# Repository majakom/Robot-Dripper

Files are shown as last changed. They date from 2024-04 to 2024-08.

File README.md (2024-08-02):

# Robot-Dripper

Project made for Computer System Architecture at Poznań University of Technology.

## General description of the project

The goal of this project was to create a robot that is a coffee machine.
Project was finally presented at Poznań Univeristy of Technology at the event RoboDay.

This repository includes code for both [arduino UNO prototype](motor_control) and [atmega 8 final version](ask) of the robot.<br />
[This directory](motiondetector) leads to code used for testing the motion detector.<br />
[Here](Eagle) You can find an Eagle board and schemtic for the PCB.

## Links to documentation

Entire documentation of the proccess available under the following link:<br />
https://docs.google.com/document/d/1cahnLlo-Lx6Y2TZ_qJPBwkHGlFsrj01b/edit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

Short film on YouTube which depicts the process of creating the coffee machine:<br />
https://www.youtube.com/watch?v=yFp_BpbxnpI

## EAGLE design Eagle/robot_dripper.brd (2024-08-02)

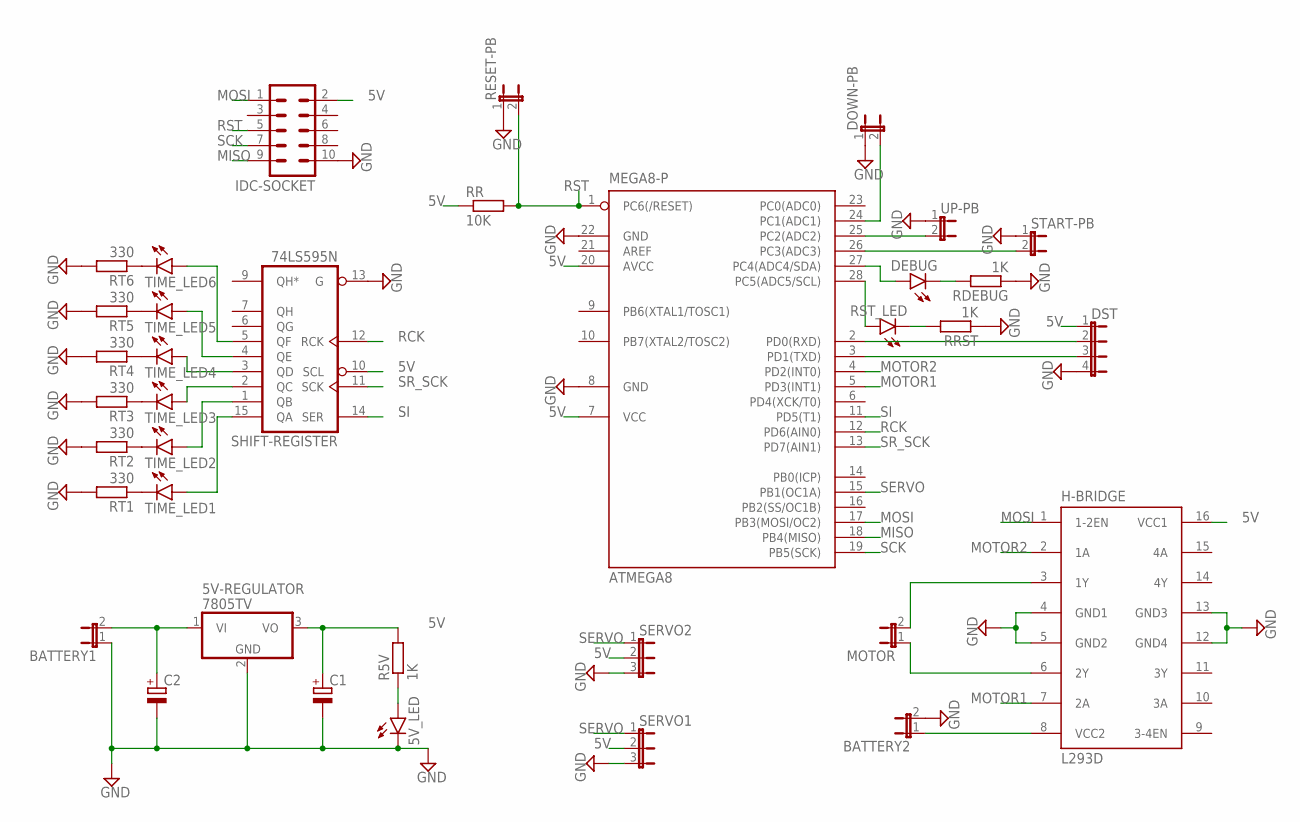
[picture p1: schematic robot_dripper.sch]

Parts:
5V-REGULATOR: 7805TV; TO220V
5V_LED: LED5MM
ATMEGA8: MEGA8-P; DIL28-3
BATTERY1, BATTERY2: JP1E; JP1
C1, C2: CPOL-EUE5-10.5; E5-10,5
DEBUG: LED5MM
DOWN-PB: JP1E; JP1
DST: JP4E; JP4
H-BRIDGE: L293D; DIL16
IDC-SOCKET: ML10
MOTOR: JP1E; JP1
R5V: 1K; 0207/10
RDEBUG: 1K; 0207/10
RESET-PB: JP1E; JP1
RR: 10K; 0207/10
RRST: 1K; 0207/10
RST_LED: LED5MM
RT1, RT2, RT3, RT4, RT5, RT6: 330; 0207/10
SERVO1, SERVO2: JP2E; JP2
SHIFT-REGISTER: 74LS595N; DIL16
START-PB: JP1E; JP1
TIME_LED1, TIME_LED2, TIME_LED3, TIME_LED4, TIME_LED5, TIME_LED6: LED5MM
UP-PB: JP1E; JP1

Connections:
5V: 5V-REGULATOR.3 (VO), ATMEGA8.7 (VCC), ATMEGA8.20 (AVCC), C1.+, DST.1, H-BRIDGE.16 (VCC1), IDC-SOCKET.2, R5V.2, RR.1, SERVO1.2, SERVO2.2, SHIFT-REGISTER.10 (SCL), SHIFT-REGISTER.16 (VCC)
GND: 5V-REGULATOR.2 (GND), 5V_LED.K (C), ATMEGA8.8 (GND), ATMEGA8.22 (GND), BATTERY1.1, BATTERY2.2, C1.-, C2.-, DOWN-PB.1, DST.4, H-BRIDGE.4 (GND1), H-BRIDGE.5 (GND2), H-BRIDGE.12 (GND4), H-BRIDGE.13 (GND3), IDC-SOCKET.10, RDEBUG.1, RESET-PB.1, RRST.1, RT1.2, RT2.2, RT3.2, RT4.2, RT5.2, RT6.2, SERVO1.3, SERVO2.3, SHIFT-REGISTER.8 (GND), SHIFT-REGISTER.13 (G), START-PB.1, UP-PB.1
MISO: ATMEGA8.18 (PB4(MISO)), IDC-SOCKET.9
MOSI: ATMEGA8.17 (PB3(MOSI/OC2)), H-BRIDGE.1 (1-2EN), IDC-SOCKET.1
MOTOR1: ATMEGA8.5 (PD3(INT1)), H-BRIDGE.7 (2A)
MOTOR2: ATMEGA8.4 (PD2(INT0)), H-BRIDGE.2 (1A)
unnamed: ATMEGA8.28 (PC5(ADC5/SCL)), RST_LED.A
unnamed: 5V_LED.A, R5V.1
unnamed: RRST.2, RST_LED.K (C)
unnamed: ATMEGA8.27 (PC4(ADC4/SDA)), DEBUG.A
unnamed: DEBUG.K (C), RDEBUG.2
unnamed: ATMEGA8.26 (PC3(ADC3)), START-PB.2
unnamed: ATMEGA8.25 (PC2(ADC2)), UP-PB.2
unnamed: ATMEGA8.24 (PC1(ADC1)), DOWN-PB.2
unnamed: ATMEGA8.2 (PD0(RXD)), DST.2
unnamed: ATMEGA8.3 (PD1(TXD)), DST.3
unnamed: H-BRIDGE.6 (2Y), MOTOR.1
unnamed: SHIFT-REGISTER.15 (QA), TIME_LED1.A
unnamed: SHIFT-REGISTER.1 (QB), TIME_LED2.A
unnamed: SHIFT-REGISTER.2 (QC), TIME_LED3.A
unnamed: H-BRIDGE.3 (1Y), MOTOR.2
unnamed: SHIFT-REGISTER.3 (QD), TIME_LED4.A
unnamed: SHIFT-REGISTER.4 (QE), TIME_LED5.A
unnamed: SHIFT-REGISTER.5 (QF), TIME_LED6.A
unnamed: RT1.1, TIME_LED1.K (C)
unnamed: RT2.1, TIME_LED2.K (C)
unnamed: RT3.1, TIME_LED3.K (C)
unnamed: RT4.1, TIME_LED4.K (C)
unnamed: RT5.1, TIME_LED5.K (C)
unnamed: RT6.1, TIME_LED6.K (C)
unnamed: BATTERY2.1, H-BRIDGE.8 (VCC2)
unnamed: 5V-REGULATOR.1 (VI), BATTERY1.2, C2.+
RCK: ATMEGA8.12 (PD6(AIN0)), SHIFT-REGISTER.12 (RCK)
RST: ATMEGA8.1 (PC6(/RESET)), IDC-SOCKET.5, RESET-PB.2, RR.2
SCK: ATMEGA8.19 (PB5(SCK)), IDC-SOCKET.7
SERVO: ATMEGA8.15 (PB1(OC1A)), SERVO1.1, SERVO2.1
SI: ATMEGA8.11 (PD5(T1)), SHIFT-REGISTER.14 (SER)
SR_SCK: ATMEGA8.13 (PD7(AIN1)), SHIFT-REGISTER.11 (SCK)

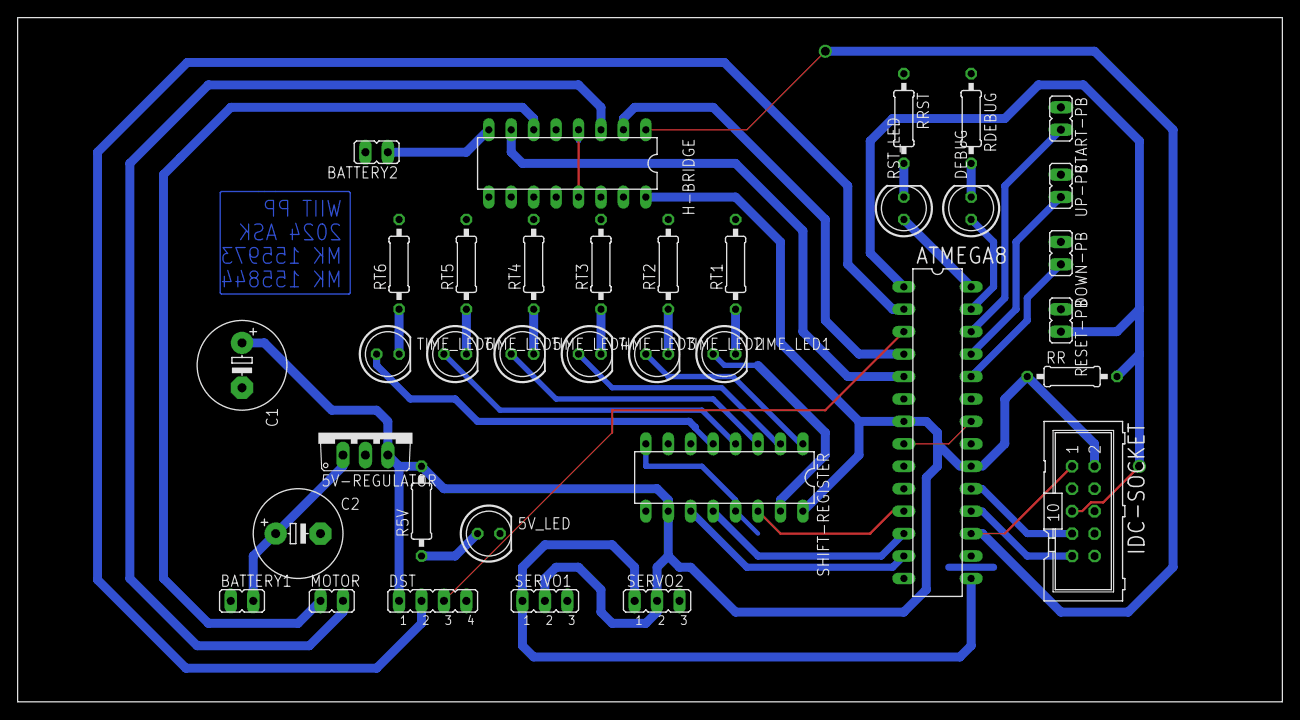
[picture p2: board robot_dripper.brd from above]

Board: 2 copper layers, 143.2 x 77.5 mm, 36 parts (0 on the bottom side), 38 nets.

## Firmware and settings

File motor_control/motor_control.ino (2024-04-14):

#include<Servo.h>
Servo servo;
// give a name to digital pin 2, which has a pushbutton attached
const int pushButton = 2;
//red button
const int pushButtonRed = 5;
const int pushButtonReturn = 6;

// the transistor which controls the motor will be attached to digital pin 9
const int motorControl = 9;
const int motorControlR = 10;

const int trigPin = 3;
const int echoPin = 4;
int distance, duration;

int distVector[300] = {1000,1000,1000,1000,1000,1000,1000,1000,1000,1000,1000,1000,1000,1000,1000,1000,1000,1000,1000,1000,1000,1000,1000,1000,1000,1000,1000,1000,1000,1000,1000,1000,1000,1000,1000,1000,1000,1000,1000,1000,1000,1000,1000,1000,1000,1000,1000,1000,1000,1000,1000,1000,1000,1000,1000,1000,1000,1000,1000,1000,1000,1000,1000,1000,1000,1000,1000,1000,1000,1000,1000,1000,1000,1000,1000,1000,1000,1000,1000,1000,1000,1000,1000,1000,1000,1000,1000,1000,1000,1000,1000,1000,1000,1000,1000,1000,1000,1000,1000,1000,1000,1000,1000,1000,1000,1000,1000,1000,1000,1000,1000,1000,1000,1000,1000,1000,1000,1000,1000,1000,1000,1000,1000,1000,1000,1000,1000,1000,1000,1000,1000,1000,1000,1000,1000,1000,1000,1000,1000,1000,1000,1000,1000,1000,1000,1000,1000,1000,1000,1000,1000,1000,1000,1000,1000,1000,1000,1000,1000,1000,1000,1000,1000,1000,1000,1000,1000,1000,1000,1000,1000,1000,1000,1000,1000,1000,1000,1000,1000,1000,1000,1000,1000,1000,1000,1000,1000,1000,1000,1000,1000,1000,1000,1000,1000,1000,1000,1000,1000,1000,1000,1000,1000,1000,1000,1000,1000,1000,1000,1000,1000,1000,1000,1000,1000,1000,1000,1000,1000,1000,1000,1000,1000,1000,1000,1000,1000,1000,1000,1000,1000,1000,1000,1000,1000,1000,1000,1000,1000,10001000,1000,1000,1000,1000,1000,1000,1000,1000,1000,1000,1000,1000,1000,1000,1000,1000,1000,1000,1000,1000,1000,1000,1000,1000,1000,1000,1000,1000,1000,1000,1000,1000,1000,1000,1000,1000,1000,1000,1000,1000,1000,1000,1000,1000,1000,1000,1000,1000,1000,1000,1000,1000,1000,1000,1000,1000,1000,1000,1000};
int index = 0;
bool stop = false;
const int debug = 12;

//controling the spacetime
long int time = 0;
long int waitTime = 0;
int stage = 0;

const int angleStop = 179; // Możliwe że dla drugiego serwa będzie od 0 do 180, ale fajnie by było gdyby było tak samo
const int angleStart = 0;
int angle = angleStart;

const int debugWaitStart = 13;

// the setup routine runs once when you press reset:
void setup() {
  servo.attach(11);

  servo.write(angleStart); 
  pinMode(debugWaitStart, OUTPUT);

  pinMode(pushButtonRed, INPUT);
  pinMode(pushButtonReturn, INPUT);

  pinMode(debug, OUTPUT); //diode
  // make the pushbutton's pin an input:
  pinMode(pushButton, INPUT);

  // make the transistor's pin an output:
  pinMode(motorControl, OUTPUT);  
  pinMode(motorControlR, OUTPUT);
  
  //defining trigger pin in the distance detector
  pinMode(trigPin, OUTPUT);

  //defining echo pin in the distance detector
  pinMode(echoPin, INPUT);

  Serial.begin(9600);
  Serial.println(
      "Distance measurement using Arduino Uno.");
  delay(500);

}

// the loop routine runs over and over again forever:
void loop() {
   
  distance = measureDistance();
  if(digitalRead(pushButtonRed) == HIGH) {
    stage = 0;
    time = 0;
    waitTime = 20;
    analogWrite(motorControl, 0);
    analogWrite(motorControlR, 0);
    digitalWrite(debugWaitStart, LOW);
  }

  if (!wait()){
    switch (stage){
      case 0:
        // Czekaj na przycisk i czekaj minutę - rozpoczęcie robienia kawy
        // nalanie wody możnaby dodać
        if (digitalRead(pushButtonReturn) == HIGH){
          stage = 6;
          //analogWrite(motorControl, 255);
          //delay(50);
        }
        analogWrite(motorControl, 0);
        analogWrite(motorControlR, 0);
        if(digitalRead(pushButton) == HIGH){
          servo.write(angleStart);
          waitTime = 8580; // (możnaby dołożyć leda albo fancy wyświetlacz)
          digitalWrite(debugWaitStart, HIGH);
          Serial.println("0->1");
          stage = 1;
        }
        delay(1); 
        break;
      case 1:
        // Zamieszaj w jedną stronę
        digitalWrite(debugWaitStart, LOW);
        analogWrite(motorControl, 255);
        delay(50);
        waitTime = 715; // mieszanie przez 5s
        Serial.println("1->2");
        stage = 2;
        break;
      case 2:
        // Zamieszaj w drugą (bo mostek H)
        analogWrite(motorControl, 0);
        delay(50);
        analogWrite(motorControlR,255);
        delay(50);
        waitTime = 715; // mieszanie przez 5s
        Serial.println("2->3");
        stage = 3;
        break;
      case 3:
        // Poczekaj do niecałej reszty z 15 sekund
        analogWrite(motorControlR, 0);
        delay(50);
        waitTime = 430;
        Serial.println("3->4");
        stage = 4;
        break;
      case 4:
        // Obniż do wykrycia kubka
        stop = false;
        for(int a = 0; a < 300; a++) {
          if(distVector[a] > 7) {
            stop = false;
            break;
          } else {
            stop = true;
          }
        }
        if(!stop) {
          angle++;
          servo.write(angle);
          if (angle==angleStop) {
            Serial.println("4->5");
            stage = 5;
          }
          waitTime = 2;
        } else {
          Serial.println("4->5");
          stage = 5;
        }
        break;
      case 5:
        // Poczekaj na przelanie
        digitalWrite(debugWaitStart, HIGH);
        waitTime = 17160;
        Serial.println("5->6");
        stage = 6;
        break;
      case 6:
        // Podnieś
        digitalWrite(debugWaitStart, LOW);
        angle--;
        servo.write(angle);
        if (angle<=angleStart) {
          Serial.println("6->0");
          stage = 0;
        }
        waitTime = 2;
        break;
    }
  }
  // if (!wait()){
  //   switch (stage){
  //     case 0:
  //       //Czekaj na przycisk - rozpoczęcie robienia kawy
  //       servo.write(0);
  //       if(digitalRead(pushButton) == HIGH){
  //         analogWrite(motorControl, 255);
  //         delay(50);
  //         Serial.println("0->1");
  //         stage = 1;
  //       } else {
  //         analogWrite(motorControl,0);
  //         analogWrite(motorControlR,0);
  //       }
  //       delay(1); 
  //       break;
  //     case 1:
  //       //Obniż do wykrycia kubka
  //       stop = false;
  //       //detecting interruption
  //       for(int a = 0; a < 5; a++) {
  //         if(distVector[a] > 7) {
  //           stop = false;
  //           break;
  //         } else {
  //           stop = true;
  //         }
  //       }
  //       if(stop) {
  //         analogWrite(motorControl,0);
  //         Serial.println("1->2");
  //         stage = 2;
  //       }
        
  //       break;
  //     case 2:
  //       //Wlej wodę
  //       if (angle < 120) {
  //         servo.write(angle);
  //         angle++;
  //         waitTime = 2;
  //       } else if (angle == 120) {
  //         servo.write(angle);
  //         angle++;
  //         waitTime = 100;
  //       } else if (angle <= 240) {
  //           servo.write(120-(angle-120));
  //           angle++;
  //           waitTime = 2;
  //       } else {
  //         angle = 0;
  //         stage = 3;
  //         waitTime = 1000; // Poczekaj minutę (nie wiem czy to dokładnie 60000)
  //         Serial.println("2->3");
  //       }
  //       break;
  //     case 3:
        
  //       //Zamieszaj
  //       stage = 4;
  //       waitTime = 1000; // Poczekaj 10 sekund (przy założeniu że mieszanie trwa 5 sekund)
  //       Serial.println("3->4");
  //       break;
  //     case 4:
  //       //Obniż
  //       analogWrite(motorControl,255);
  //       stage = 5;
  //       Serial.println("4->5");
  //       waitTime = 1000; 
  //       break;
  //     case 5:
  //       // Poczekaj 2 minuty aż się przeleje
  //       analogWrite(motorControl,0);
  //       stage = 6;
  //       Serial.println("5->6");
  //       waitTime = 1000;
  //       break;
  //     case 6:
  //       //Podnieś
  //       analogWrite(motorControlR,255);
  //       Serial.println("6->0");
  //       stage = 0;
  //       waitTime = 1000;
  //       break;
  //   }
  // }
  
  // // read the state of the button and check if it is pressed
  // if(digitalRead(pushButton) == HIGH){
  //   analogWrite(motorControl, 255);
  //   delay(150);
  // }
  // delay(1);        // delay in between reads for stability
  // stop = false;
  // //detecting interruption
  // for(int a = 0; a < 5; a++) {
  //   if(distVector[a] > 10) {
  //     stop = false;
  //     break;
  //   } else {
  //     stop = true;
  //   }
  // }
  

  // //servo added with pouring water and coffee
  // delay(60000);
  // //string coffee - another servo
  // delay(15000);
  // // down
  // delay(120000);
  // //wait until everything goes through
  
  // if(stop) {
  //   analogWrite(motorControl,0);
  //   delay(100);
  //   for(int x = 0; x <= 255; x+=10){
  //     analogWrite(motorControlR, 255);
  //     delay(50);
  //   }
  //   delay(100);
  //   analogWrite(motorControlR,0);
  // }


  delay(1);

}


int measureDistance() {

  digitalWrite(trigPin, LOW);
  delayMicroseconds(2);
  digitalWrite(trigPin, HIGH);
  delayMicroseconds(10);
  digitalWrite(trigPin, LOW);
  duration = pulseIn(echoPin,HIGH);
  distance = duration*0.0344/2;
  // Serial.print("Distance: ");
  // Serial.print(
  //     distance); // Print the output in serial monitor
  // Serial.println(" cm");

  if(index == 300) {
    index = 0;
  }

  distVector[index++] = distance;


  return distance;
}


bool wait(){
  if (time == waitTime) {
    time = 0;
    waitTime = 0;
    return false;
  } else {
    time ++;
    return true;
  }
}

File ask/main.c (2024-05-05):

#include <avr/io.h>
#include <util/delay.h>
#include <avr/eeprom.h>
#include <stdio.h>
# define INDEX_DISTANCE 13
# define PROGRESS_STEPS 6

const int MIN_ANGLE = 41;
const int MAX_ANGLE = 3;

const int MAX_MOTOR = 140;
const int MIN_MOTOR = 105;

void init();
void initLEDs();
void initButtons();
void initServoControl();
void initDistanceMeasurement();
void initMotorControl();
void initShiftRegister();
void blinkResetLed();
void saveAngle();
void sendPulse();
unsigned long measurePulse();
unsigned long measureDistance();
void motorStop();
void motorForward(uint8_t dutyCycle);
void motorBackward(uint8_t dutyCycle);
void progressTime();
void writeShiftRegister();
void finishCoffee();
void startCoffee();
void servoUP();
void servoDOWN();
int distanceStop();
void stir1();
void stir2();

int stage = 0;
int distVector[INDEX_DISTANCE];
int indexVector = 0;
int stop = 0;
unsigned long distance = 0;
int progress = 0;


int main(void) {
	init();
	while(1) {
		saveAngle();
		distance = measureDistance();

		_delay_ms(1);
		switch (stage){
		case 0:
			if (bit_is_clear(PINC,PC3)){
				startCoffee();
				_delay_ms(30000);
				progressTime();
				_delay_ms(30000);
				progressTime();
			} else if (bit_is_clear(PINC,PC2)){
				servoUP();
			} else if (bit_is_clear(PINC,PC1)){
				servoDOWN();
			}
			break;
		case 1:
			stir1();
			_delay_ms(3000);
			break;
		case 2:
			stir2();
			_delay_ms(3000);
			break;
		case 3:
			motorStop();
			stage = 4;
			_delay_ms(2000);
			break;
		case 4:
			servoDOWN();
			stage = 5;
			break;
		case 5:
			PORTC |= (1<<PC4);
			_delay_ms(15000);
			progressTime();
			_delay_ms(30000);
			progressTime();
			_delay_ms(30000);
			progressTime();
			_delay_ms(30000);
			progressTime();
			PORTC &= ~(1<<PC4);
			stage = 6;
			break;
		case 6:
			servoUP();
			finishCoffee();
			progressTime();
			stage = 0;
			break;
		}
		_delay_ms(1);
	}
}

void init(void){
	initLEDs();
	initButtons();
	initServoControl();
	initDistanceMeasurement();
	initMotorControl();
	initShiftRegister();
	blinkResetLed();
}

void initLEDs(){
	DDRC |= (1<<PC5); // Set Reset Led Output
	DDRC |= (1<<PC4); // Set Debug Led Output
}

void initButtons(){
	DDRC &= ~(1<<PC3); // Set Start Button Input
	PORTC |= (1<<PC3); // Enale Start Button Pull-up
	DDRC &= ~(1<<PC2); // Set Servo-Up Button Input
	PORTC |= (1<<PC2); // Enable Servo-Up Button Pull-up
	DDRC &= ~(1<<PC1); // Set Servo-Down Button Input
	PORTC |= (1<<PC1); // Enable Servo-Down Button Pull-up
}

void initServoControl(){
	DDRB |= (1<<PB1); // Set Servo Pin
	// Set Timer
	TCCR1A |= (1<<COM1A1)|(1<<WGM11);
	TCCR1B |= (1<<WGM13)|(1<<WGM12)|(1<<CS11)|(1<<CS10);
	ICR1 = (F_CPU/64UL/60ul)-1;
	uint8_t byteRead = eeprom_read_byte((uint8_t*)23); // read the byte in location 23
	if (byteRead>=MAX_ANGLE && byteRead <= MIN_ANGLE){
		OCR1A = byteRead; // Set angle to last value (if in memory)
	} else {
		OCR1A = MAX_ANGLE; // Set default angle if nothing in memory
	}
}

void initDistanceMeasurement(){
	DDRD |= (1 << PD0); // Set trigger pin (PD0) as output
	DDRD &= ~(1 << PD1); // Set echo pin (PD1) as input
	for (int i = 0; i < INDEX_DISTANCE; i++){
		distVector[i] = 1000;
	}
}

void initMotorControl(){
	TCCR2 |= (1 << WGM20) | (1 << WGM21) | (1 << COM21) | (1 << CS22); // Set Fast PWM mode with non-inverted output
	DDRB |= (1 << PB3); // Set OC2 (PB3) as output
	DDRD |= (1<<PD2); // Set Direction 1 Control Output
	DDRD |= (1<<PD3); // Set Direction 2 Control Output
	OCR2 = 0;
	motorStop();
}

void initShiftRegister() {
	DDRD |= (1<<PD5); // Set SI/DS Output
	DDRD |= (1<<PD6); // Set RCK/ST_CP Output
	DDRD |= (1<<PD7); // Set SCK/SH_CP
	writeShiftRegister();
}

void blinkResetLed(){
	for (int i=0; i<10; i++){
		PORTC ^= (1<<PC5);
		_delay_ms(100);
	}
}

void saveAngle(){
	eeprom_write_byte ((uint8_t*) 23, OCR1A); //  write OCR1A (angle) to location 23 of the EEPROM
}

void sendPulse() {
    PORTD |= (1 << PD0); // Set trigger pin (PD0) HIGH
    _delay_us(10); // Wait for 10 microseconds
    PORTD &= ~(1 << PD0); // Set trigger pin LOW
}

unsigned long measurePulse() {
    unsigned long pulseDuration = 0;
    while (!(PIND & (1 << PD1))); // Wait for the echo pin to go HIGH
    while (PIND & (1 << PD1)) pulseDuration++; // Measure pulse duration
    return pulseDuration;
}

unsigned long measureDistance(){
	sendPulse(); // Send pulse to trigger the sensor
	unsigned long duration = measurePulse(); // Measure the pulse duration
	// Calculate distance using duration and the speed of sound
	unsigned long new_distance = (duration * 343) / (2*1000); // Convert to centimeters

	if (indexVector == INDEX_DISTANCE){
		indexVector = 0;
	}
	distVector[indexVector++] = distance;
	return new_distance;
}

void motorStop(){
	OCR2 = 0;
	PORTD &= ~(1<<PD2);
	PORTD &= ~(1<<PD3);
}
void motorForward(uint8_t dutyCycle){
	PORTD &= ~(1<<PD2);
	PORTD |= (1<<PD3);
	OCR2 = dutyCycle;

}
void motorBackward(uint8_t dutyCycle){
	PORTD &= ~(1<<PD3);
	PORTD |= (1<<PD2);
	OCR2 = dutyCycle;
}

void startCoffee(){
	PORTC |= (1<<PC4);
	servoUP();
	stage = 1;
}

void servoUP(){
	for (int i = OCR1A; i >= MAX_ANGLE; i--){
		OCR1A = i;
		_delay_ms(100);
		saveAngle();
	}
	saveAngle();
}

void servoDOWN(){
	for (int i = 0; i < INDEX_DISTANCE; i++){
		distVector[i] = 1000;
	}
	_delay_ms(10);
	for (int i = OCR1A; i <= MIN_ANGLE; i++){
		if (!distanceStop()){
			OCR1A = i;
			_delay_ms(90);
			saveAngle();
		}
		else {
			saveAngle();
			break;
		}
	}
}

int distanceStop(){
	distance = measureDistance();
	int stop = 1;
	for(int j = 0; j < INDEX_DISTANCE; j++) {
		if(distVector[j] > 6) {
			stop = 0;
		}
	}
	return stop;
}

void stir1(){
	PORTC &= ~(1<<PC4);
	motorStop();
	_delay_ms(50);
	motorForward(MAX_MOTOR);
	_delay_ms(2000);
	for (int i = MAX_MOTOR; i >= MIN_MOTOR; i--){
		motorForward(i);
		_delay_ms(10);
	}
	motorStop();
	_delay_ms(1000);
	stage = 2;
}

void stir2(){
	motorStop();
	_delay_ms(50);
	motorBackward(MAX_MOTOR);
	_delay_ms(1000);
	for (int i = MAX_MOTOR; i >= MIN_MOTOR; i--){
		motorBackward(i);
		_delay_ms(10);
	}
	stage = 3;
}

void progressTime() {
	progress++;
	if (progress == PROGRESS_STEPS+1) {
		progress = 0;
	}
	writeShiftRegister();
}

void writeShiftRegister(){
	PORTD &= ~(1<<PD6);
	if (progress){
		PORTD &= ~(1<<PD7);
		PORTD |= (1<<PD5);
		PORTD |= (1<<PD7);
	} else {
		PORTD &= ~(1<<PD5);
		for (int i = 0; i<8; i++){
			PORTD &= ~(1<<PD7);
			PORTD |= (1<<PD7);
		}
	}
	PORTD |= (1<<PD6);
}

void finishCoffee(){
	for (int j = 0; j < 10; j++){
		for (int i = 0; i < PROGRESS_STEPS; i++){
			PORTD &= ~(1<<PD6);
			PORTD &= ~(1<<PD7);
			PORTD |= (1<<PD5);
			PORTD |= (1<<PD7);
			PORTD |= (1<<PD6);
			_delay_ms(35);
		}
		for (int i = 0; i < PROGRESS_STEPS; i++){
			PORTD &= ~(1<<PD6);
			PORTD &= ~(1<<PD7);
			PORTD &= ~(1<<PD5);
			PORTD |= (1<<PD7);
			PORTD |= (1<<PD6);
			_delay_ms(35);
		}
	}

}

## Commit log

2024-03-22 Added motor controler
2024-03-22 Added servo
2024-04-12 Changed code for servo control
2024-04-13 Added button for reset
    [motor_control.ino]
2024-08-02 Added Eagle board and schematic
    [robot_dripper.brd, robot_dripper.sch]
